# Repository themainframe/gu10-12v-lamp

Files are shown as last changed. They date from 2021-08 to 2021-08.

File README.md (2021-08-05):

# `gu10-12v-lamp`

This is a [GU10](https://en.wikipedia.org/wiki/Bi-pin_lamp_base#Types) style lamp for **12V** use, ideal for situations where a mains lighting system has been converted to 12V. The driverless design makes them compatible with PWM-based or voltage-based dimming. An integral diode bridge allows insertion in either orientation. They are made with standard FR4 PCB rather than Aluminium for lower cost.

This is a KiCad (5.1.9-0-10_14) project.

Gerbers, schematic & BOM may be found in the `outputs` directory.

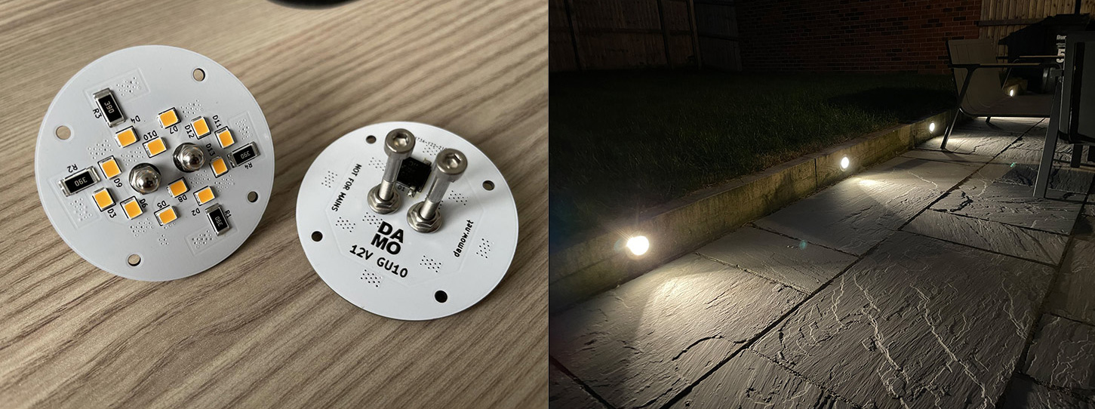
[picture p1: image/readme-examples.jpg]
PCB Examples and Usage


After production, a sandwich of **M3** 30mm (or shorter/longer, depending on your fitting depth) standard cap-head machine screws, bolts and washers can be fitted through the central holes to produce GU10 compatible "lugs" for insertion into a standard GU10 bayonet lamp holder.

For outdoor use I'd suggest conformally coating the boards on the top and bottom sides _after_ insertion of the M3 fasteners.

**These lamps are for 12V DC only. Do not connect these lamps to mains voltage.**

Standard 2835 LED chips are used (I used 3000K 150mA 2.95Vf [CREE J Series® JB2835AWT-W-U30GA0000-N0000001](https://www.digikey.co.uk/en/products/detail/cree-inc/JB2835AWT-W-U30GA0000-N0000001/10820387)). LEDs are in 4 groups of (3 chips in series) with a resistor for each group, with each group seeing a ~11V supply voltage after the diode bridge drop. I'd recommend using 39Ω 2512-size resistors (for a LED current of 50mA) and a total system current of 200mA (~2.4W including power dissipated by the diode bridge). The lamps stay at a sensible temperature at this power.

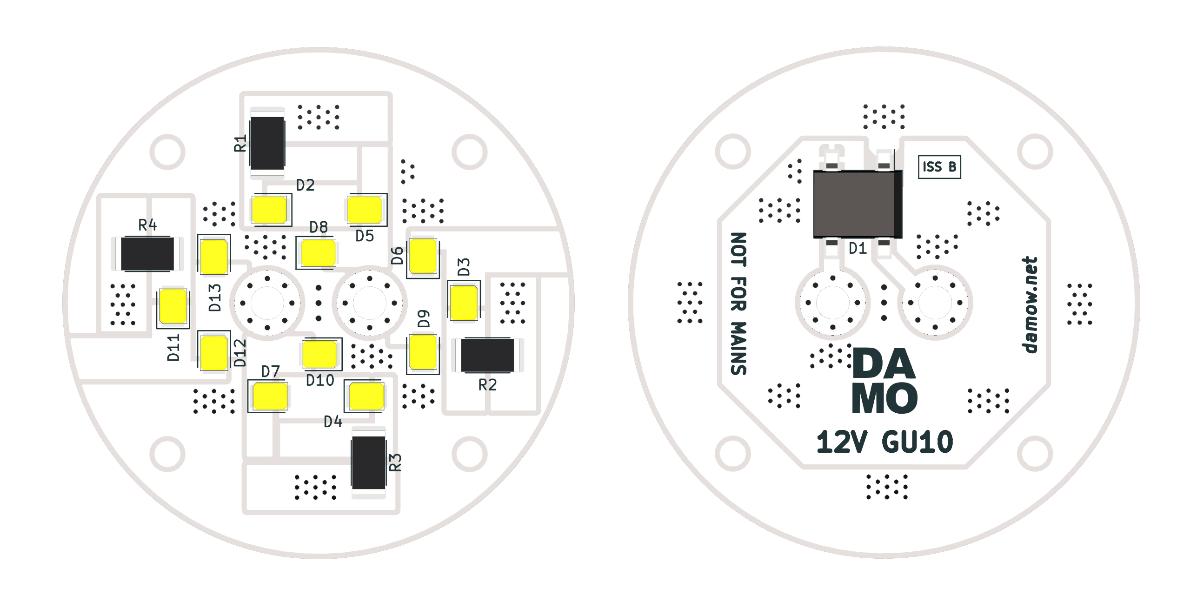
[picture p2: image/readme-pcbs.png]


## Revisions

* **Issue A** - Initial release (used in the example photos above).
* **Issue B** - Improved layout for better thermals.

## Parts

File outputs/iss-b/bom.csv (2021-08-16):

Component | Description | Part | References | Value | Footprint | Quantity Per PCB | Datasheet | Vendor 10of GBP | Vendor | Vendor SKU
1 | Diode bridge, +ve/-ve/AC/AC | D_Bridge_+-AA | D1 | Diode Bridge | Diode_Bridge_Vishay_DFS | 1 | ~ | 0.41 | Digi-Key | DF01SA-E3/77GICT-ND
2 | Light emitting diode | LED | D2 D3 D4 D5 D6 D7 D8 D9 D10 D11 D12 D13 | LED | LED_PLCC_2835 | 12 | ~ | 0.01500 | Digi-Key | 2138-JB2835AWT-W-U30GA0000-N0000001CT-ND
3 | Resistor | R | R1 R2 R3 R4 | 39R | R_2512_6332Metric | 4 | ~ | 0.181 | Digi-Key | RMCF2512JT39R0CT-ND
Component Groups: | 3
Component Count: | 17
Fitted Components: | 17
Number of PCBs: | 1
Total components: | 17
Schematic Version: | ISS B
Schematic Date:
PCB Variant: | udefault
BoM Date: | Monday, 16 August 2021 at 18:13:15
Schematic Source: | gu10-12v-lamp.sch
KiCad Version: | Eeschema (5.1.9-0-10_14)

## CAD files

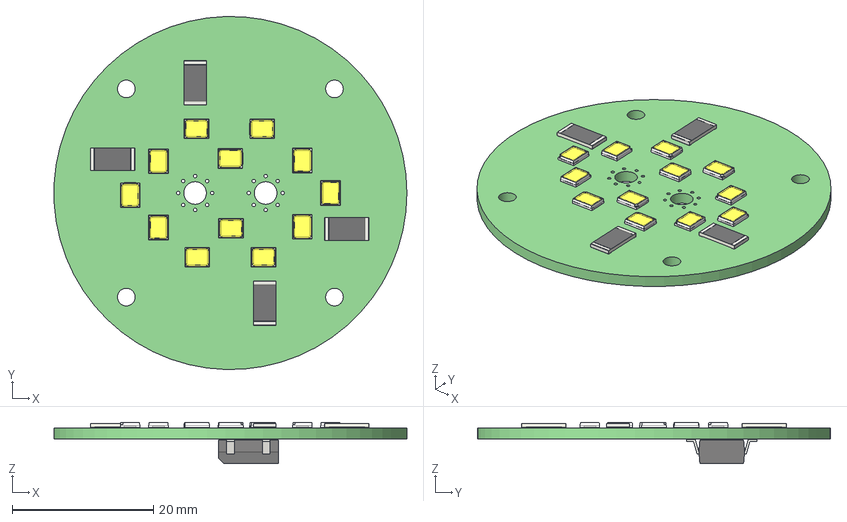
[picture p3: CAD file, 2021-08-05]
outputs/iss-b/3d/gu10-12v-lamp.step
50.0 x 50.0 x 5.82 mm

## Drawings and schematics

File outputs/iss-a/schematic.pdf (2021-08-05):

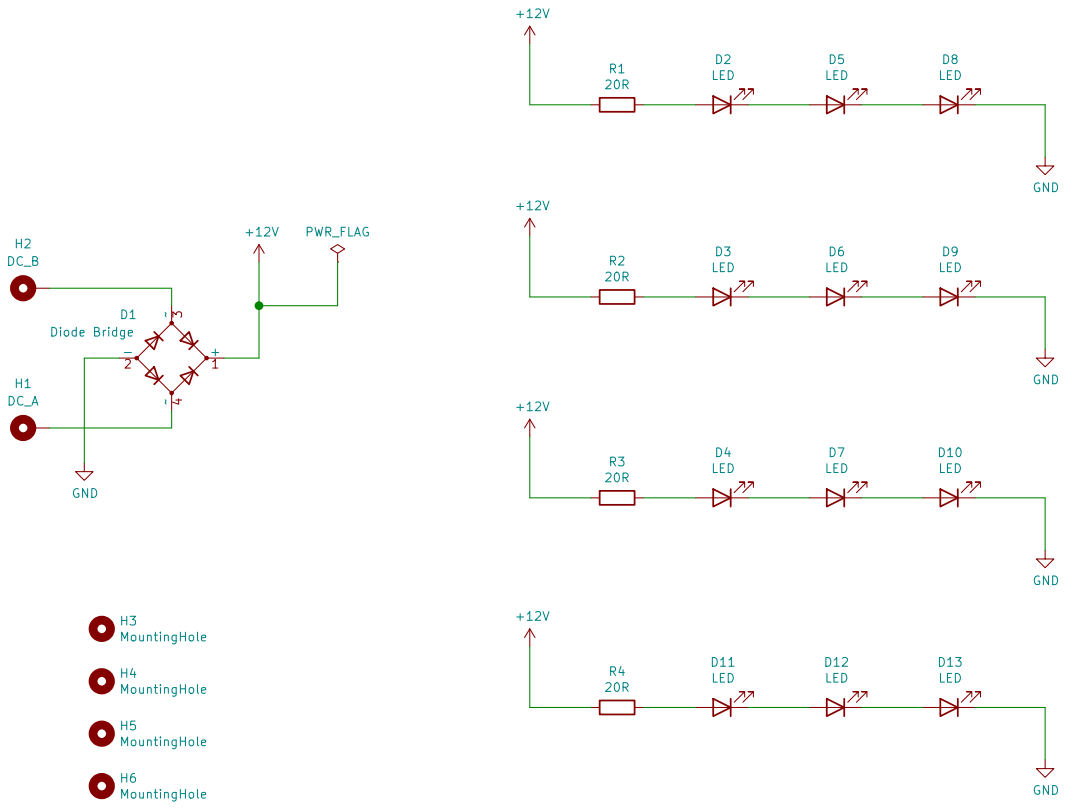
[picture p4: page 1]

File: gu10-12v-lamp.sch Sheet: / damow.net H1 DC_A

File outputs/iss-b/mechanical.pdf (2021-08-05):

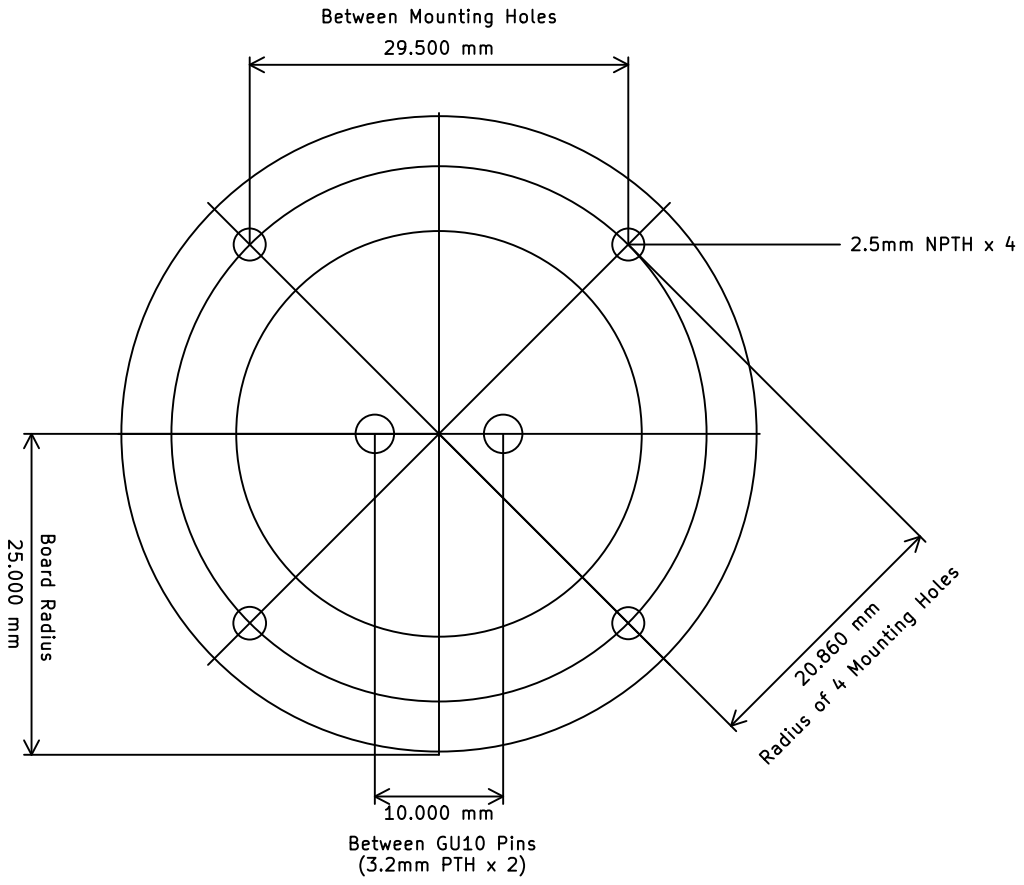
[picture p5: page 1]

(3.2mm PTH x 2) Between Mounting Holes

Radius of 4 Mounting Holes Board Radius 25.000 mm

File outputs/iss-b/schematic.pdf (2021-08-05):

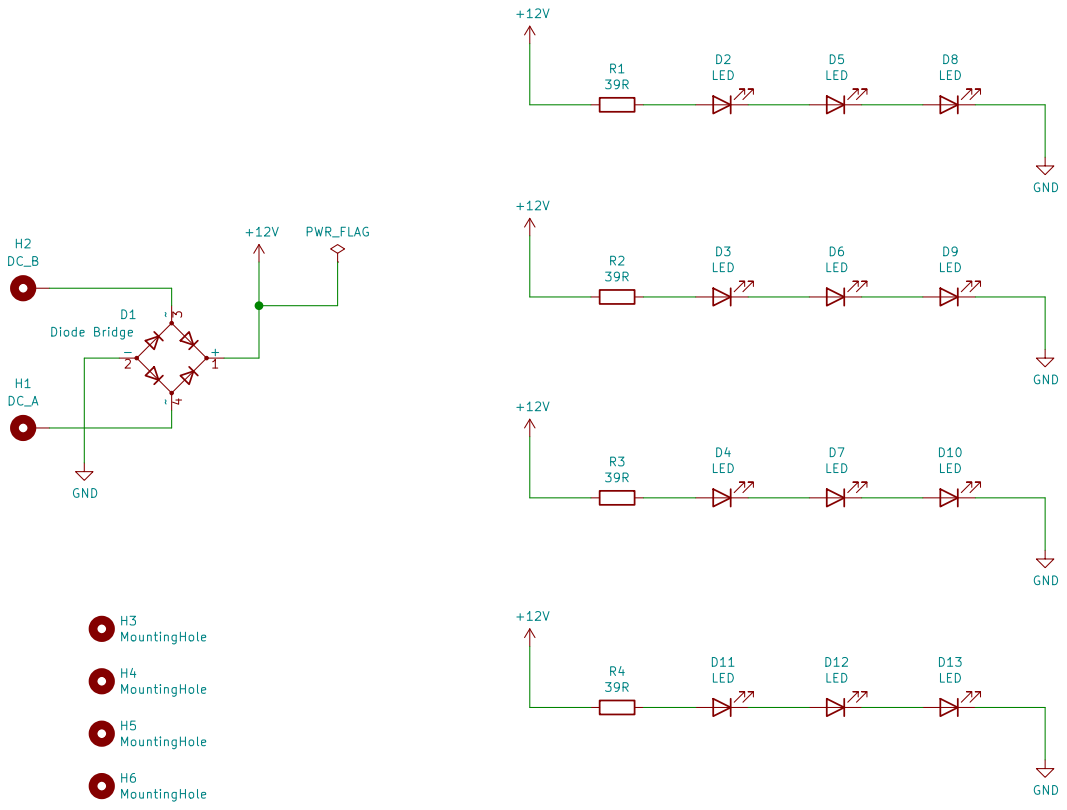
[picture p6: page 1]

File: gu10-12v-lamp.sch Sheet: / damow.net H1 DC_A

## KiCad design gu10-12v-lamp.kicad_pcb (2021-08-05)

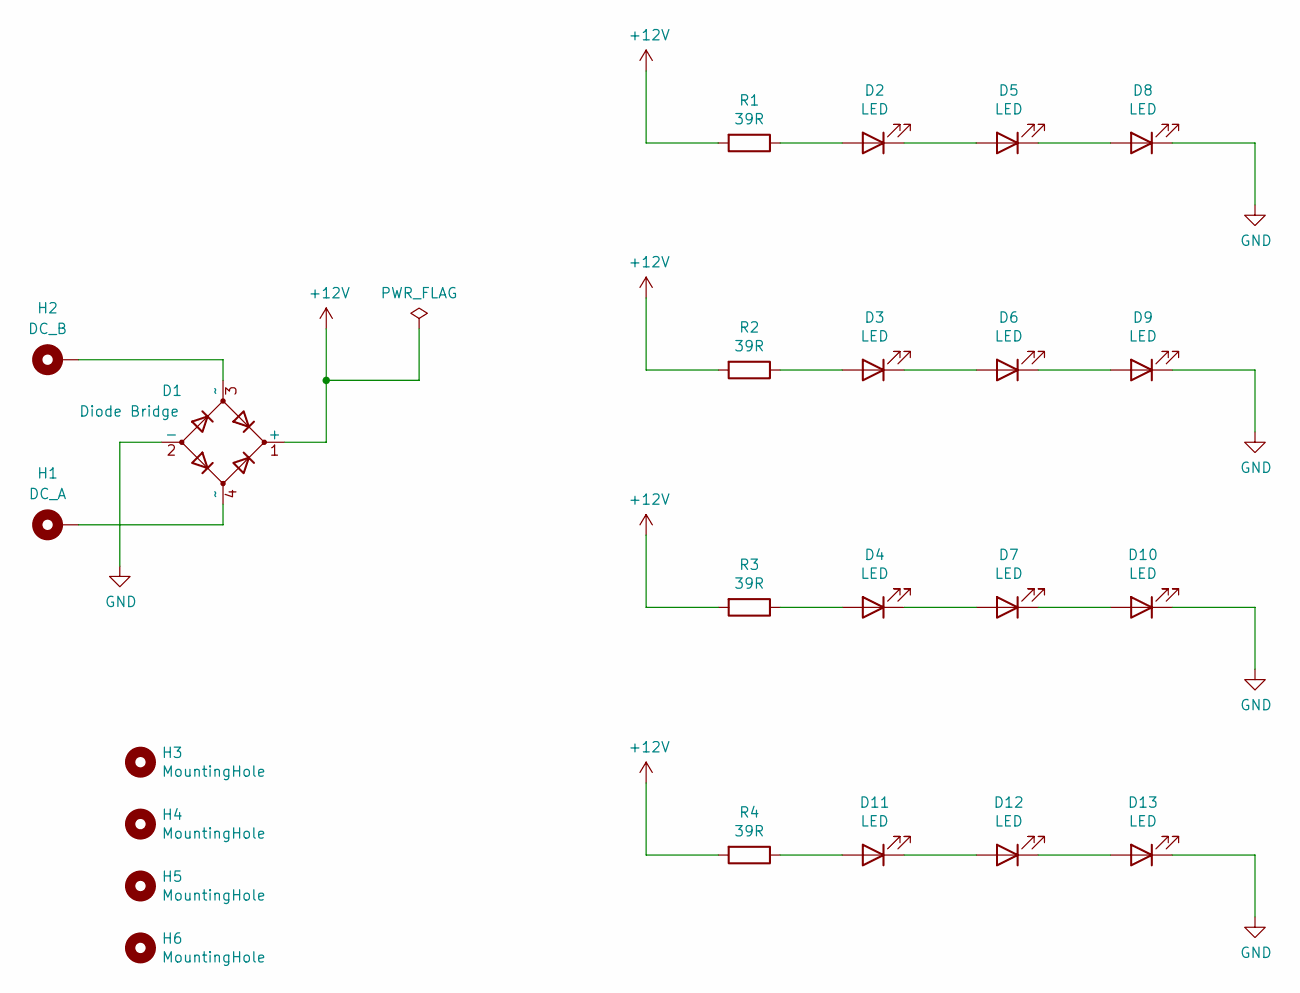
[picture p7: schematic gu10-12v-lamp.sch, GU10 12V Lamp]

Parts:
D1: Diode Bridge; Diode_Bridge_Vishay_DFS
D2, D3, D4, D5, D6, D7, D8, D9, D10, D11, D12, D13: LED; LED_PLCC_2835
H1: DC_A; MountingHole_3.2mm_M3_Pad_Via
H2: DC_B; MountingHole_3.2mm_M3_Pad_Via
H3, H4, H5, H6: MountingHole; MountingHole_2.5mm
R1, R2, R3, R4: 39R; R_2512_6332Metric

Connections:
+12V: D1.1 (+), R1.2, R2.2, R3.2, R4.2
GND: D1.2 (-), D8.1 (K), D9.1 (K), D10.1 (K), D13.1 (K)
unnamed: D1.3 (~~), H2.1
unnamed: D1.4 (~~), H1.1
unnamed: D2.1 (K), D5.2 (A)
unnamed: D2.2 (A), R1.1
unnamed: D3.1 (K), D6.2 (A)
unnamed: D3.2 (A), R2.1
unnamed: D4.1 (K), D7.2 (A)
unnamed: D4.2 (A), R3.1
unnamed: D5.1 (K), D8.2 (A)
unnamed: D6.1 (K), D9.2 (A)
unnamed: D7.1 (K), D10.2 (A)
unnamed: D11.1 (K), D12.2 (A)
unnamed: D11.2 (A), R4.1
unnamed: D12.1 (K), D13.2 (A)

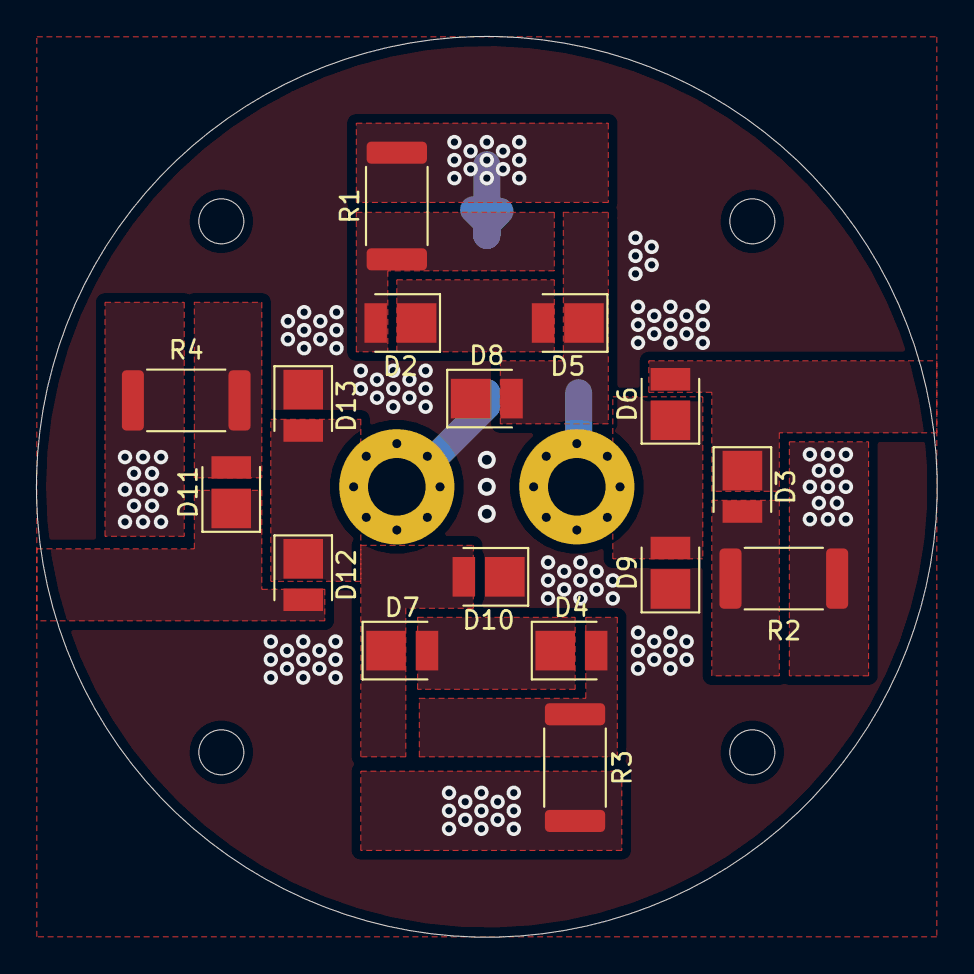
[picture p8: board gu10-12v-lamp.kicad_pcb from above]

Board: 2 copper layers, 50.0 x 50.0 mm, 23 parts (1 on the bottom side), 16 nets.

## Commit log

2021-06-06 Add: Initial Commit
    [User Library-LED 2835.IGS, gu10-12v-lamp.kicad_pcb, gu10-12v-lamp.sch]
2021-08-05 Add: Gerber files
    [gu10-12v-lamp-B_Cu.gbr, gu10-12v-lamp-B_Mask.gbr, gu10-12v-lamp-B_Paste.gbr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]
2021-08-05 Add: Issue B assets
    [gu10-12v-lamp-B_Cu.gbr, gu10-12v-lamp-B_Mask.gbr, gu10-12v-lamp-B_Paste.gbr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]
2021-08-05 Fix: Power calcs
2021-08-16 Add: BOM
    [bom.csv]
